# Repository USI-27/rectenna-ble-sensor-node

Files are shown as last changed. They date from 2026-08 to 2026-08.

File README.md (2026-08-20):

# Energy Harvesting BLE Environmental Sensor Node
### A Batteryless IoT Node Powered by a Pyramidal Rectenna WPT Front End

> **Status:** Hardware bring up complete, mathematical framework finalized, research paper in preparation (unpublished). This repository documents the design rationale, schematic, and PCB layout of the sensor node hardware.

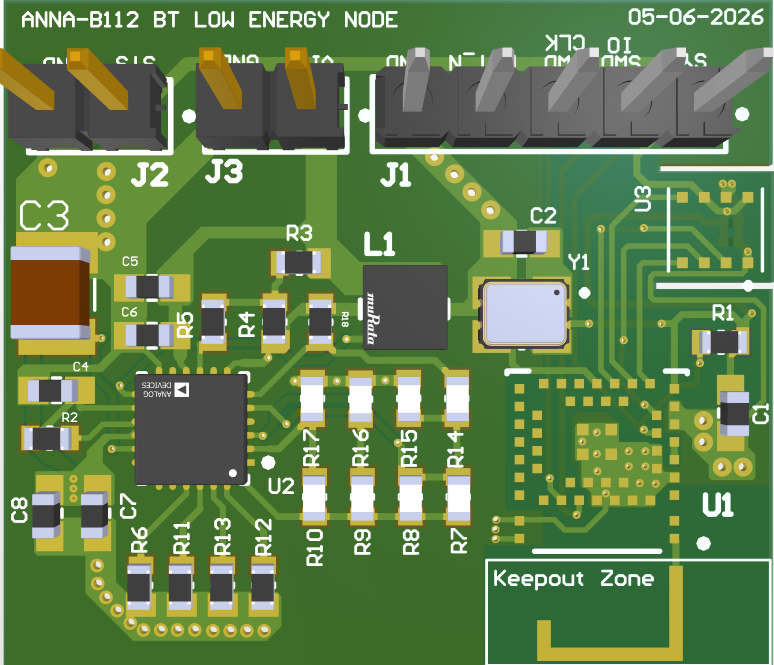
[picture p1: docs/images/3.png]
Assembled board


---

## 1. Project Summary

This project implements a **batteryless Bluetooth Low Energy (BLE) sensor node** designed to be powered entirely by RF energy harvested through a custom **pyramidal multi sector rectenna** (Wireless Power Transfer front end, documented separately in the accompanying research work). The rectenna's rectified DC output feeds an ultra low power energy harvesting PMU, which charges a supercapacitor and regulates power for a BLE microcontroller and an environmental sensor.

The system demonstrates **Simultaneous Wireless Information and Power Transfer (SWIPT)**: the same RF link that delivers power also allows the node to periodically transmit BLE beacons containing live temperature/humidity/gas sensor data, with no battery in the loop.

```
[ RF Transmitter ] --(WPT)--> [ Pyramidal Rectenna Array ] --(rectified DC)--> [ This PCB ]
                                                                                     |
                                                        +----------------------------+----------------------------+
                                                        |                            |                            |
                                                [ ADP5091 PMU ]           [ ANNA-B112 BLE SoC ]         [ BME688 Sensor ]
                                                (harvest + MPPT +          (application MCU +           (temp / humidity /
                                                 supercap storage)         BLE radio + SWD debug)         pressure / gas)
```

---

## 2. Repository Structure (suggested)

```
├── hardware/
│   ├── schematic/          # Altium .SchDoc exports, PDF schematic
│   ├── pcb/                # Altium .PcbDoc, layer stack, Gerbers
│   └── bom/                # Bill of materials
├── firmware/                # ANNA-B112 firmware (BLE beacon + sensor read)
├── analysis/                 # Rectenna mathematical framework, MATLAB/Python scripts
├── docs/
│   └── images/               # Photos, renders, plots (see Section 6)
└── README.md
```

---

## 3. Hardware Architecture & Design Rationale

The board is organized into three functional blocks, each shown as a separate circuit in the Altium schematic.

### 3.1 Power Management — ADP5091 Energy Harvesting Circuit

**Why this part:** The ADP5091 is an ultra low power boost regulator purpose built for harvesting from high impedance, low current sources (like a rectenna) rather than a conventional battery charger IC. It supports cold start from very low input voltages and includes Maximum Power Point Tracking (MPPT), which is essential because a rectenna's optimal output impedance shifts with incident RF power. Without MPPT, a fixed impedance load would waste most of the harvested energy.

| Net / Component | Function | Design Choice |
|---|---|---|
| `VIN` → `L1` (22 µH) → `SW` | Boost converter inductor | Sized for the ADP5091's recommended switching frequency range to balance efficiency vs. inductor size on a compact board |
| `R3`/`R4`/`R5` on `MPPT` | MPPT set ratio | Resistor divider fixes the fraction of open circuit rectenna voltage (Voc) at which the PMU regulates VIN, keeping the rectenna near its peak power transfer point regardless of incident RF level |
| `C3` (220 µF) on `BAT`/`SUPERCAP` | Primary energy reservoir | A supercapacitor is used instead of a battery, since it tolerates the highly intermittent, low current charge profile typical of RF harvesting and avoids battery degradation or replacement, keeping the node fully maintenance free |
| `R7–R10` on `SETPG`/`SETSD` | Battery good / shutdown thresholds | Resistor dividers program the exact supercap voltage window in which the system is allowed to draw load current, protecting against brown out resets of the BLE SoC |
| `R14–R17` on `SETBK`/`SETHYST` | Backup & hysteresis thresholds | Prevents rapid on/off "chattering" of the output regulator as harvested power fluctuates |
| `R18` on `TERM` | Charge termination | Limits the maximum supercap voltage to protect the storage element |
| `REG_D0`/`REG_D1` | Output voltage select | Digital pins on the ADP5091 select the regulated output rail supplied to the ANNA-B112 / BME688 |
| `C4`, `C7`, `C8` | Input/output filtering | Standard decoupling for the switching regulator stage |

### 3.2 Application Processor — ANNA-B112 (nRF52 based BLE Module)

**Why this part:** The ANNA-B112 integrates a Bluetooth 5 radio, antenna, and Cortex M0 MCU in a single certified module, minimizing RF design risk and board area. That matters on a power constrained, harvesting driven node where every extra milliamp counts.

| Net / Component | Function | Design Choice |
|---|---|---|
| `J1` (SWDIO/SWDCLK/RESET_N) | SWD programming header | Kept as a 5 pin header for in circuit firmware updates without needing to desolder the module |
| `R1` (10 kΩ) on `RESET_N` | Reset pull up | Prevents spurious resets from noise on a high impedance, low power rail |
| `Y1` (32.768 kHz) | Real time clock crystal | Used for the low power sleep/RTC timer inside the BLE stack, allowing the MCU to stay in deep sleep between BLE advertising events. This is critical for surviving on a harvested microwatt to milliamp power budget |
| `C1`, `C2` (0.1 µF) | Decoupling | Local bypass on VCC and crystal load caps |
| `MOSI_BME` / `SCLK_BME` / `MISO_BME` / `CS_BME` | SPI bus to sensor | GPIO13–15 plus a dedicated chip select line route a full duplex SPI interface to the BME688 |
| Ground pour under `U1`, RF **keepout zone** on PCB | Antenna integrity | No copper, silkscreen, or routing is placed under the module's integrated antenna area to preserve BLE radio performance |

### 3.3 Sensing — BME688 Environmental Sensor

**Why this part:** The BME688 provides temperature, humidity, pressure, and gas (VOC) sensing in one low power package, matching the "smart environmental beacon" use case for the harvested power node.

| Net / Component | Function | Design Choice |
|---|---|---|
| `CSB`/`SCK`/`SDI`/`SDO` | 4 wire SPI | SPI was chosen over I²C to avoid dependence on external pull up resistors and to reduce bus contention risk on a rail that may briefly sag during harvesting transients |
| `C9`, `C10` (100 nF) | Split VDD / VDDIO decoupling | Digital core and IO supply rails are decoupled independently to reduce switching noise coupling between them |

### 3.4 Full Schematic (PDF)

The complete Altium schematic, all three sub circuits above plus the board stack report, is available as a PDF:

📄 [**View the full schematic PDF**](docs/images/Nicla_BME688_ANNA_Project_IITrpr-1.pdf)

> GitHub renders PDFs inline when you click the link above (opens in the built in file viewer).

---

## 4. PCB Layout Notes

| Bare Top | Bare Bottom |
|---|---|
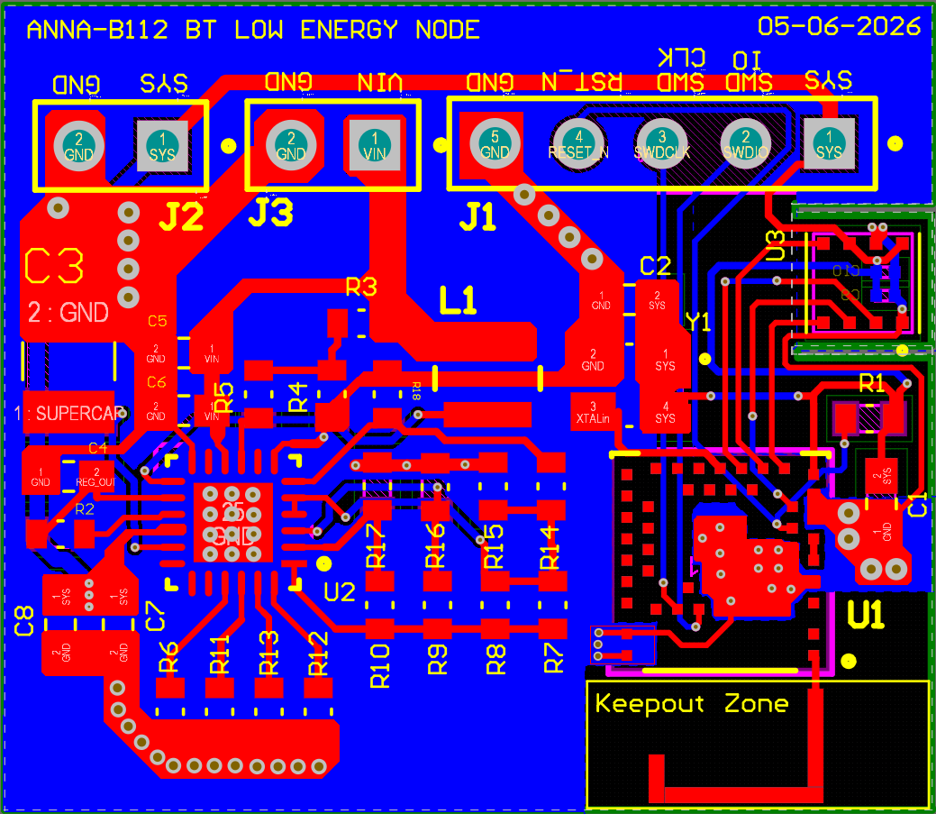
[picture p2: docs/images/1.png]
Bare top
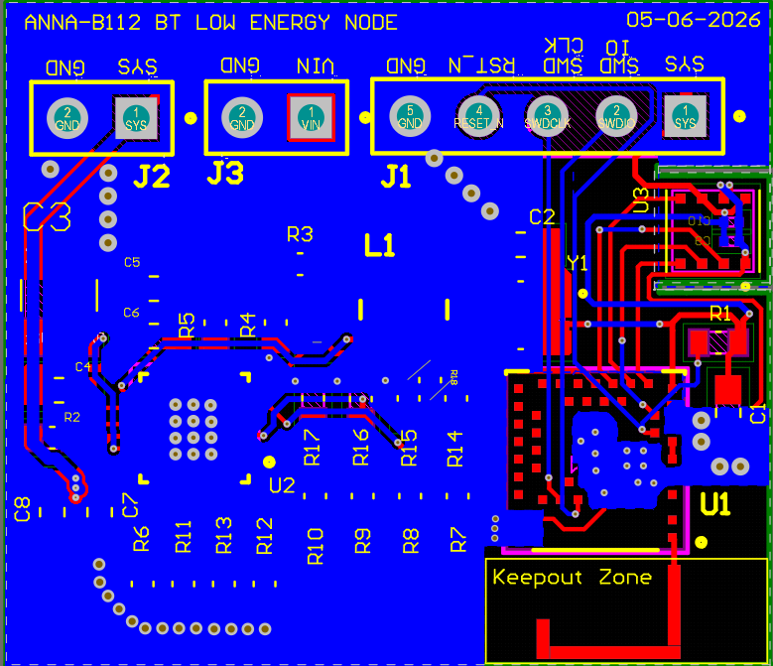
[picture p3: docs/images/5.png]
Bare bottom
|  |  |

| Assembled Top | Assembled Bottom |
|---|---|
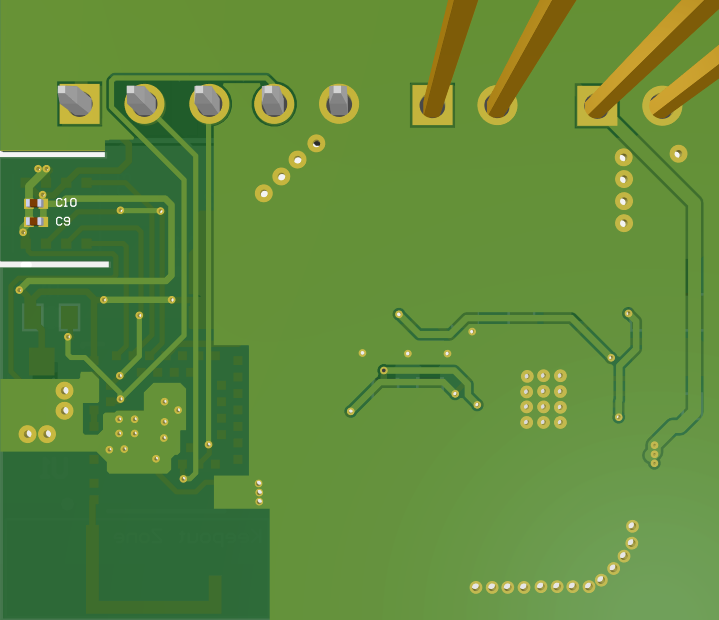
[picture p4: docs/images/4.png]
Assembled bottom
| Assembled top |  |

* **Board size:** 35 mm × 35 mm, double layer, FR4.
* **Connector placement:** `J1` (SWD), `J2`, `J3` (power in/harvester in, regulated out) are placed along one edge for easy bench access during test and debug.
* **Keepout zone:** A dedicated no copper region is reserved beneath the ANNA-B112's integrated antenna to avoid detuning the BLE radio.

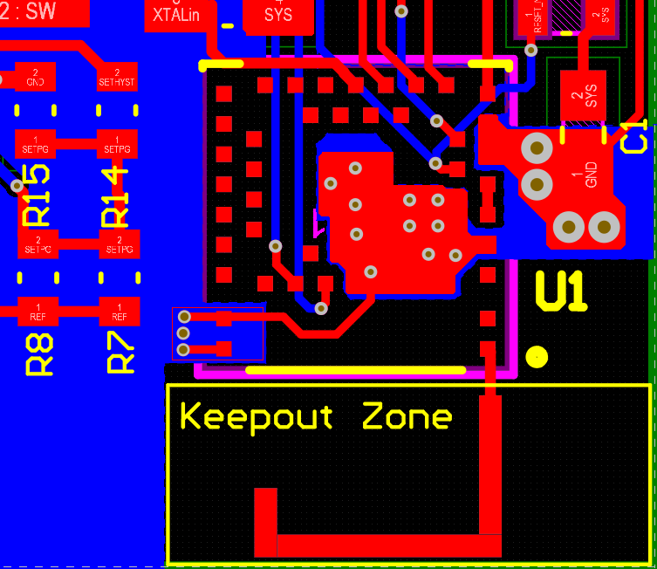
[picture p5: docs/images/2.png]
Antenna keepout close-up
  
  *No copper keepout region under the integrated BLE antenna.*

* **Component grouping:** PMU passives (`L1`, `C3` supercap, MPPT/threshold resistor networks) are clustered near `U2` to minimize switching loop area and parasitic inductance.
* A full layer stack report is included (`Board Stack Report`) for manufacturing handoff.

---

## 5. Link to the RF Energy Harvesting Research

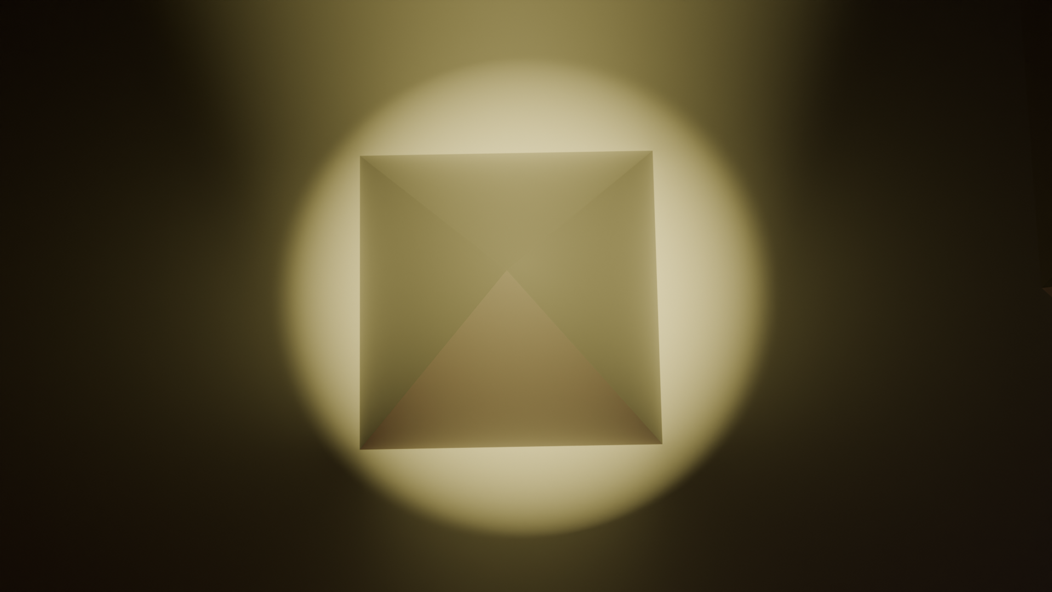
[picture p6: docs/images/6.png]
Pyramidal rectenna 3D render

*CAD render of the pyramidal multi sector rectenna (physical prototype photos pending).*

This PCB is the **load side / SWIPT receiver electronics** for a separate research effort on a plug in pyramidal multi sector rectenna system, which analytically derives:

* The optimal sector tilt angle and count for a uniform DC power pattern under lateral misalignment between transmitter and receiver.
* A dual, linearly polarized rectenna element design mitigating polarization mismatch.

The rectenna's DC output is intended to connect directly to the `VIN` harvesting input documented above. (Full derivations and measurement results are covered in the accompanying paper, currently unpublished.)

---

## 6. Photos & Media

### 6.1 PCB photos — in place

| File | Shows |
|---|---|
| `docs/images/1.png` | Bare PCB, top |
| `docs/images/5.png` | Bare PCB, bottom |
| `docs/images/3.png` | Assembled board, top (used as the hero image above) |
| `docs/images/4.png` | Assembled board, bottom |
| `docs/images/2.png` | Antenna keepout close up |

### 6.2 Rectenna prototype

| File | Shows |
|---|---|
| `docs/images/6.png` | 3D CAD render of the pyramidal rectenna |

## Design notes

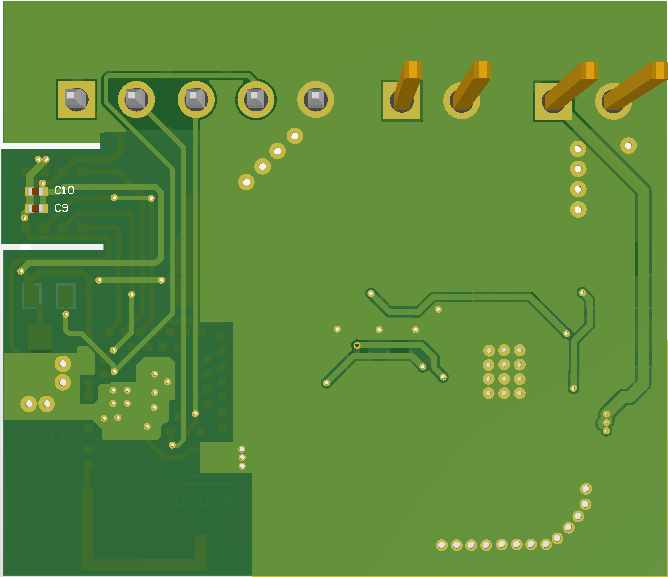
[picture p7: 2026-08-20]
Design files Altium/Nicla_BME688_ANNA_pcb_back.png

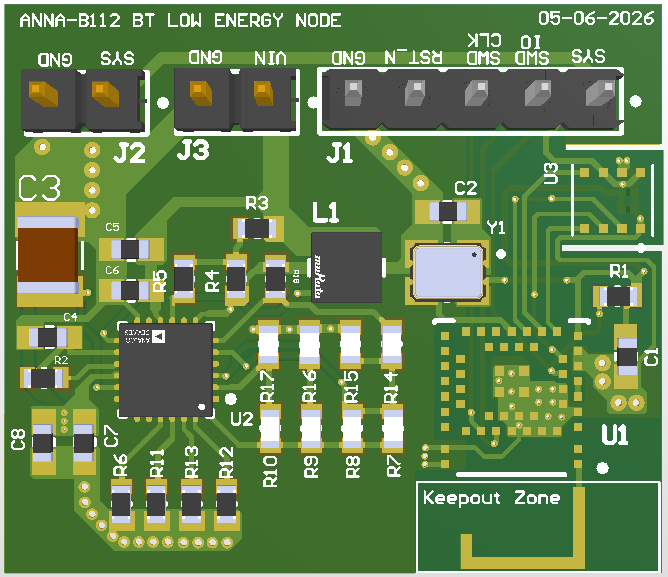
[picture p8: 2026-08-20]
Design files Altium/Nicla_BME688_ANNA_pcb.png

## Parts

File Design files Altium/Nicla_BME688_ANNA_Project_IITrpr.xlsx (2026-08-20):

Line # | Name | Description | Designator | Quantity | Manufacturer 1 | Manufacturer Part Number 1 | Manufacturer Lifecycle 1 | Supplier 1 | Supplier Part Number 1 | Supplier Unit Price 1 | Supplier Subtotal 1
1 | 0u1 | 0603 | C1, C2, C5, C8 | 4 | KEMET | C0603C104K3RACTU | Manual Solution | element14 | C0603C104K3RACTU
2 | 220u | 1210 | C3 | 1 | MURATA | GRM32ER60J227ME05L | Manual Solution | element14 | GRM32ER60J227ME05L
3 | 10u | 0603 | C4 | 1 | MURATA | GRM188R60J106ME47D | Manual Solution | element14 | GRM188R60J106ME47D
4 | 4u7 | 0603 | C6, C7 | 2 | KEMET | C0603C475K9PACTU | Manual Solution | element14 | C0603C475K9PACTU
5 | 100n | 0201 | C9, C10 | 2 | YAGEO | CC0201KRX6S4BB104 | Manual Solution | element14 | CC0201KRX6S4BB104
6 | LQH3NPZ220MMEL | Wire Wound Ferrite Inductor for Power Lines For Automotive 22μH ±20% 0.48Ω 860mA 1212 | L1 | 1 | Murata | LQH3NPZ220MMEL | Volume Production | DigiKey | 490-LQH3NPZ220MMELDKR-ND | 33.1 | 33.1
7 | 10K | 0402 | R1 | 1 | VISHAY | CRCW040210K0FKED | Manual Solution | element14 | CRCW040210K0FKED
8 | 0K | 0402 | R2, R5, R11, R12, R13 | 5 | Yageo Group | AC0402JR-071R6L | Volume Production
9 | 4.7M | 0402 | R3, R18 | 2 | VISHAY | CRCW04024M70FKED | Manual Solution | element14 | CRCW04024M70FKED
10 | 18M | 0402 | R4 | 1 | YAGEO | RC0402JR-0718ML | Manual Solution | element14 | RC0402JR-0718ML
11 | 1K | 0402 | R6 | 1 | VISHAY | CRCW04021K00FKED | Manual Solution | element14 | CRCW04021K00FKED
12 | 6M19 | 0402 | R7 | 1 | VISHAY | CRCW04026M20FKED | Manual Solution | element14 | CRCW04026M20FKED
13 | 5M9 | 0402 | R8, R10 | 2 | VISHAY | CRCW04025M90FKED | Manual Solution | element14 | CRCW04026M20FKED
14 | 6M04 | 0402 | R9 | 1 | VISHAY | RC0402FR-076M04L | Manual Solution | element14 | CRCW04026M20FKED
15 | 100K | 0402 | R14 | 1 | PANASONIC | ERJXGNJ104Y | Manual Solution | element14 | ERJXGNJ104Y
16 | 4M12 | 0402 | R15, R17 | 2 | Vishay | CRCW04024M12FKED | Volume Production | Arrow Electronics | CRCW04024M12FKED | 0.06621 | 0.13242
17 | 4M02 | 0402 | R16 | 1 | Yageo Group | AC0402FR-074M02L | Volume Production | DigiKey | 13-AC0402FR-074M02LCT-ND | 9.46 | 9.46
18 | ANNA-B112-00B | RF RECEIVER GFSK 2.4GHZ | U1 | 1 | u-blox | ANNA-B112-00B | Volume Production | Mouser | 377-ANNA-B112-00B | 960.98 | 960.98
19 | ADP5091ACPZ-1-R7 | IC BATT CHG MULTI-CHEM 24LFCSP | U2 | 1 | Analog Devices | ADP5091ACPZ-1-R7 | Volume Production | Mouser | 584-ADP5091ACPZ-1-R7 | 763.3 | 763.3
20 | BME688 | Gas sensor measuring relative humidity, barometric pressure, ambient temperature and gas (VOC) | U3 | 1 | Bosch Tools | BME688 | Volume Production | Mouser | 262-BME688 | 818.16 | 818.16
21 | S31805T-32.768K-R | 32KHz oscillator | Y1 | 1 | Aker Technology Corp | S31805T-27.000-X-R | Manual Solution | DigiKey | 2754-S31805T-27.000-X-R-ND | 2020 | 50500
 |  |  |  | 33

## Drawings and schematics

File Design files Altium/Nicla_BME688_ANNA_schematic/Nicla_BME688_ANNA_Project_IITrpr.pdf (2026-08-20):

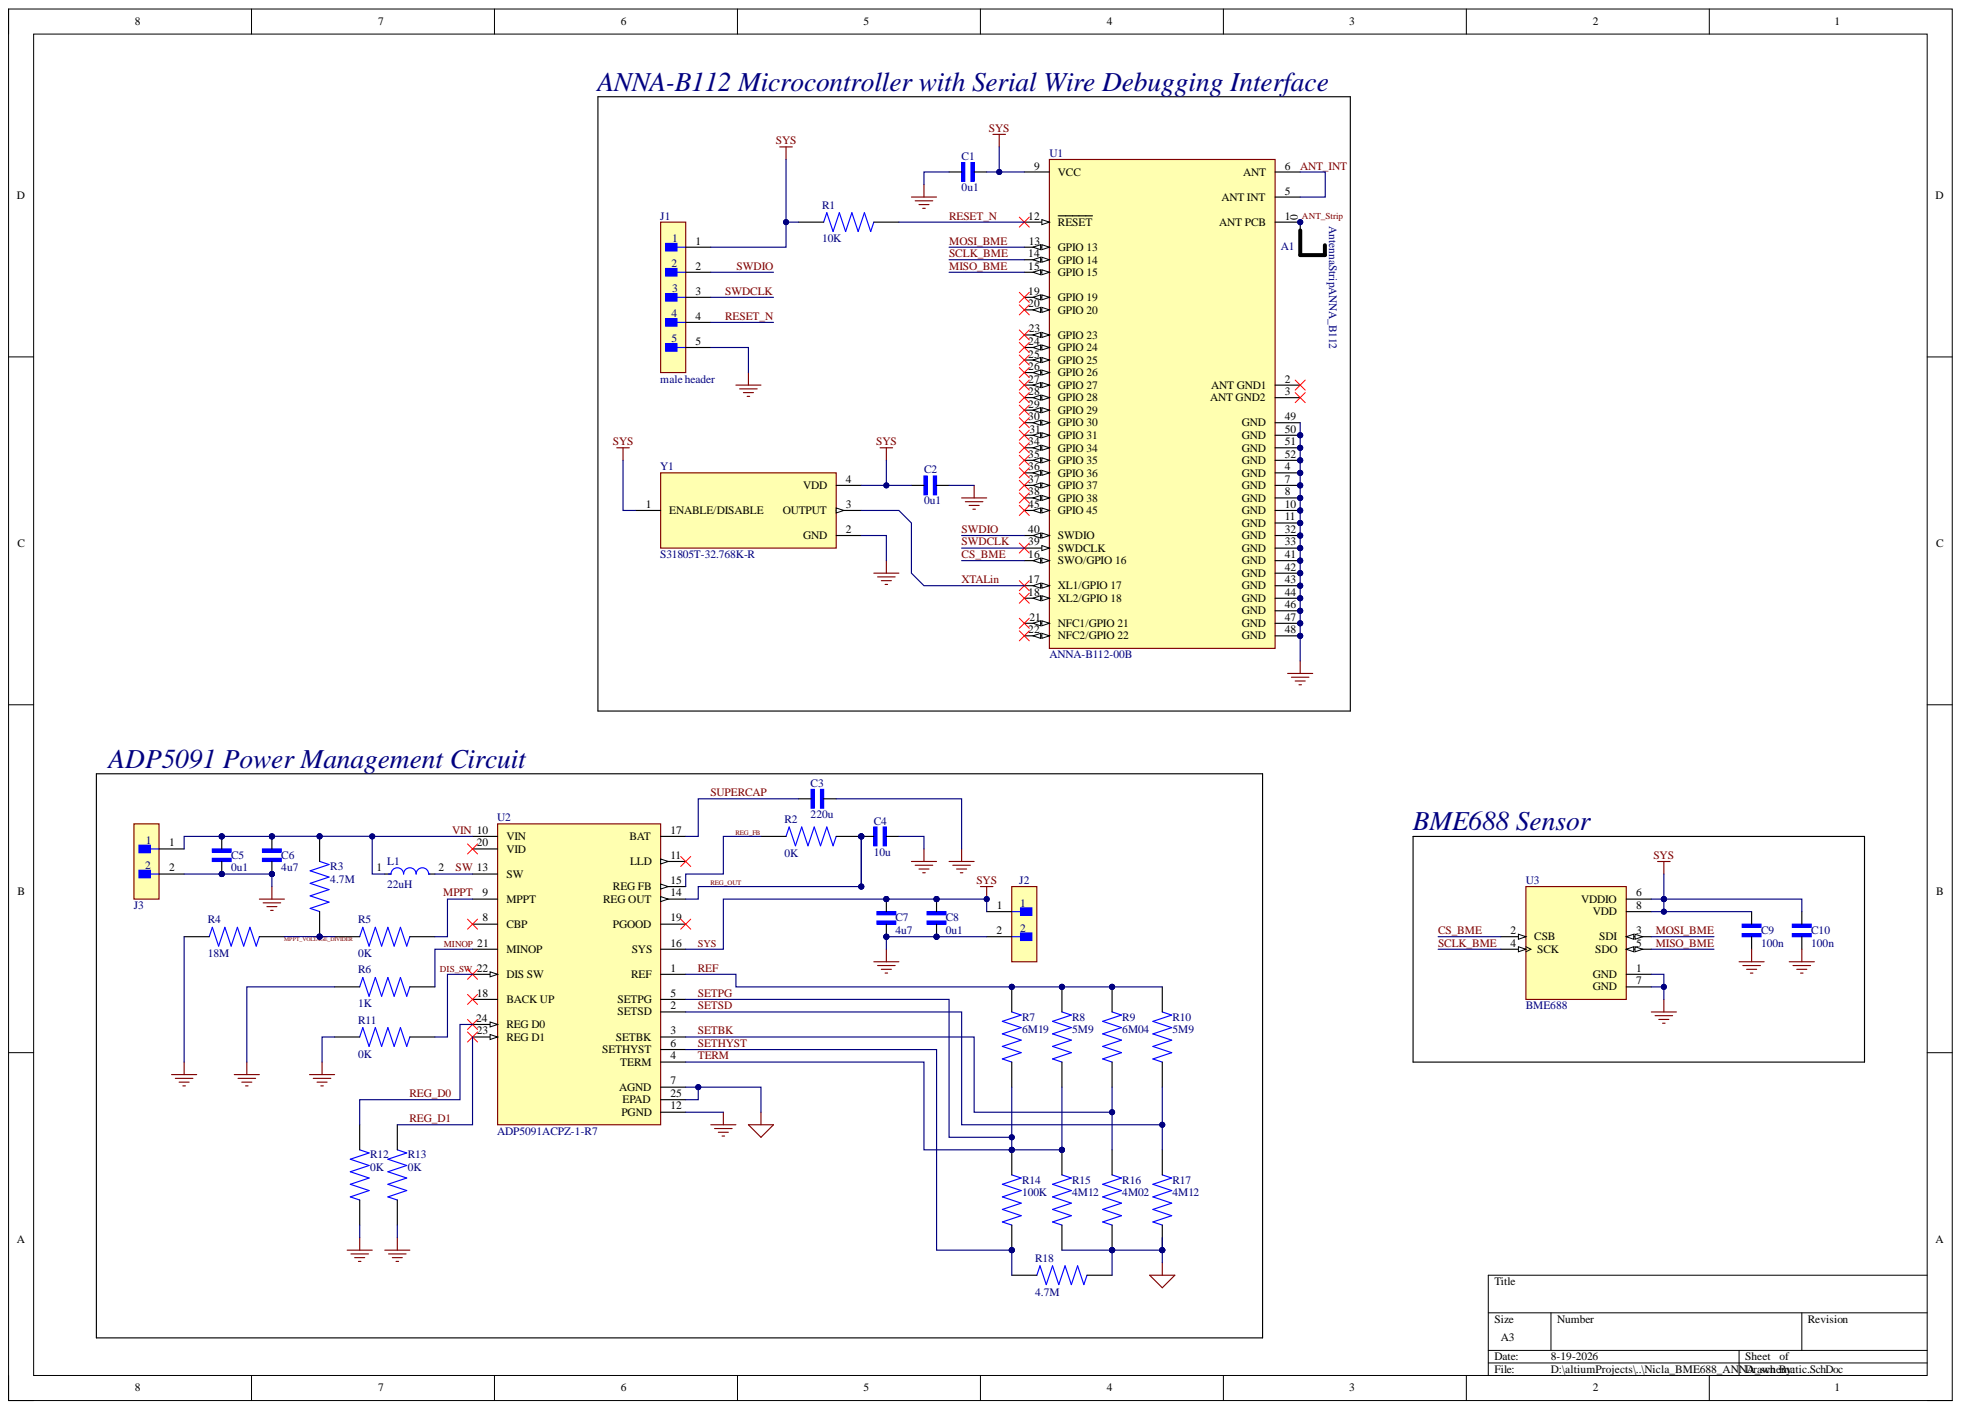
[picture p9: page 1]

ANNA-B112 Microcontroller with Serial Wire Debugging Interface

DIS_SW | DIS SW 22 | REF

BACK UP 18

REG D1 23

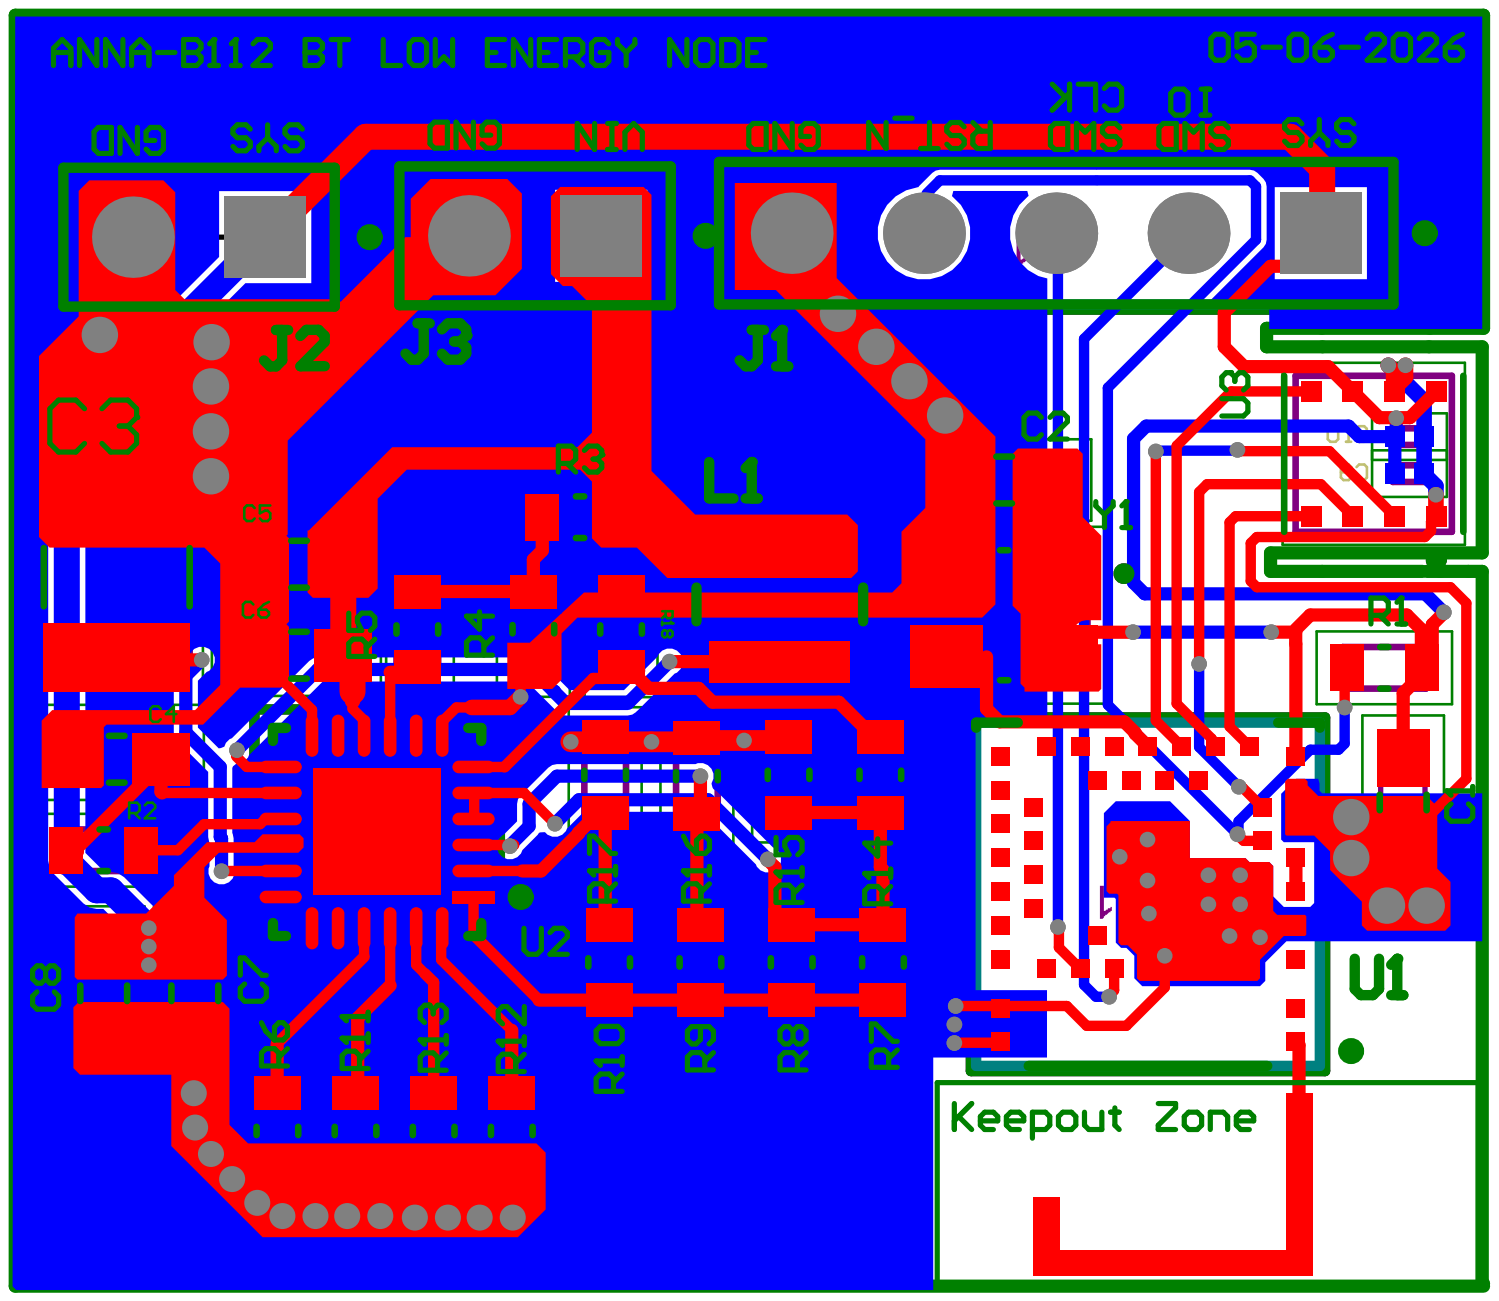
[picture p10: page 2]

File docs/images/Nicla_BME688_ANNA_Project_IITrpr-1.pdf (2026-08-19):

# ANNA-B112 Microcontroller with Serial Wire Debugging Interface


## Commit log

2026-08-19 Initial commit: BLE sensor node hardware documentation
2026-08-19 Added schematic to the repo
2026-08-20 added Altium design files
    [AntennaStripFootprint.PcbLib, AntennaStripSymbol.SchLib, Nicla_BME688_ANNA_Project_IITrpr.PrjPcb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]
